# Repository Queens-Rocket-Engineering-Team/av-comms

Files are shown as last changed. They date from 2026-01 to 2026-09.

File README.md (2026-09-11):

# Avionics Communications (Communications Module, Ground Station, etc)
> 2023-2025 Season - Communications Projects

-  Repo contains board's **firmware**, **schematics**, and related **documentation and datasheets**.
-  The **Main** branch contains current functional hardware/software
-  **Branches** contain board revisions/versions or planned features/fixes.
-  If you're contributing, **make sure you're working in a branch other than Main**

### Folder Structure
- [`/Schematics`](./Schematics/) : PCB design files (KiCad V8)  
- [`/Firmware`](./Firmware/) : Arduino C/C++ code (for STM32)
- [`/Datasheets`](./Datasheets/) : Datasheets and reference materials  
- [`.gitignore`](./.gitignore) : Build and temporary files excluded

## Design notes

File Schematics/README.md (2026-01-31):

# Schematics

This directory contains all schematics involved in this iteration of the Avionics Communications System.

## Communications Module
- Facilitates communication to ground station via LoRa

## Kuhglocke Ground Station
- Handheld ground station used for in flight telemetry and recovery

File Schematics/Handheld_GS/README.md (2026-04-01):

# Portable Ground Station

This directory contains the V1.2 revision of the ground station. It no longer has iss several known problems;

### Updates
- Removed I2C ADC, switched to ESP32-ADCs
- Using direct USB+/- for programming, removed uart bridge
- Added V_BCKP for GPS, (copied circuit from gps antenna board)

### Future Suggestions
- Look into using the MAX17043 for battery management
- Look into using TP4056 for battery charging (cheaper)
- switch to a new battery switch cause it breaks

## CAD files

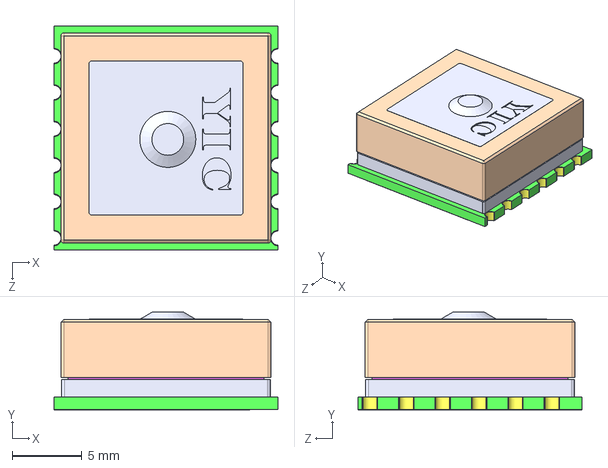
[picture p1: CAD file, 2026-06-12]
Schematics/Handheld_GS/models/STEP_YIC31616GMSGG.STEP
16.0 x 6.97 x 16.0 mm

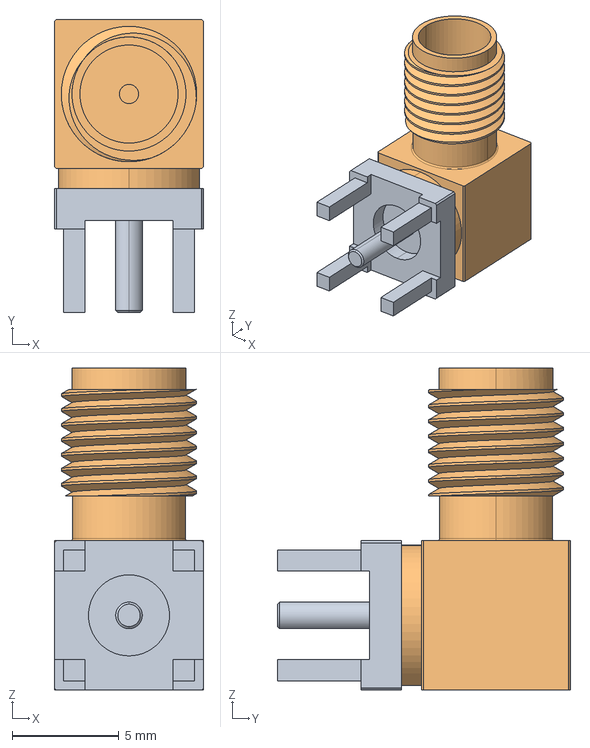
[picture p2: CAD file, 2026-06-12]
Schematics/Handheld_GS/models/pcb_smafra_ht.stp
7.00 x 13.8 x 15.1 mm

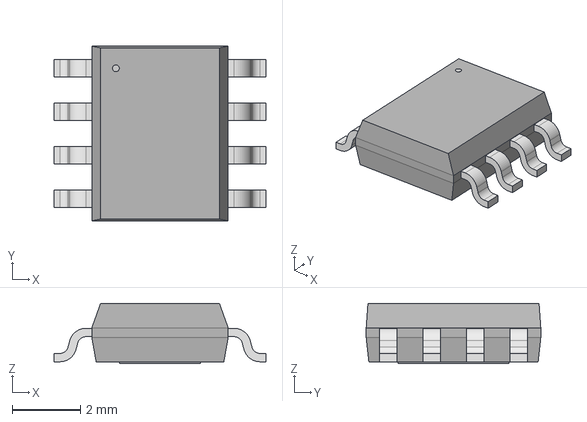
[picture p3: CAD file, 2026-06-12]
Schematics/Handheld_GS/models/ES1_ESOP-8-F__TPK.step
6.20 x 5.11 x 1.75 mm

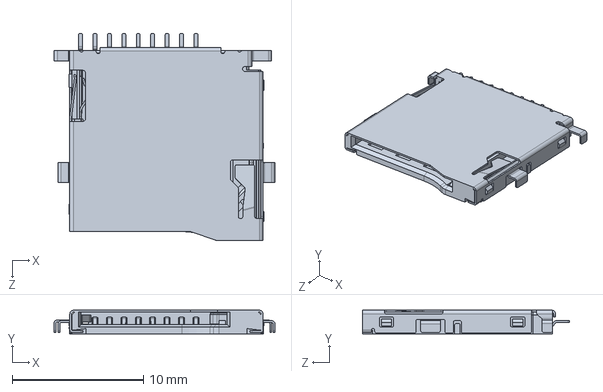
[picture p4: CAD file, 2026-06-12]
Schematics/Handheld_GS/models/Same_Sky_MSD-3-A.step
16.8 x 1.80 x 15.8 mm

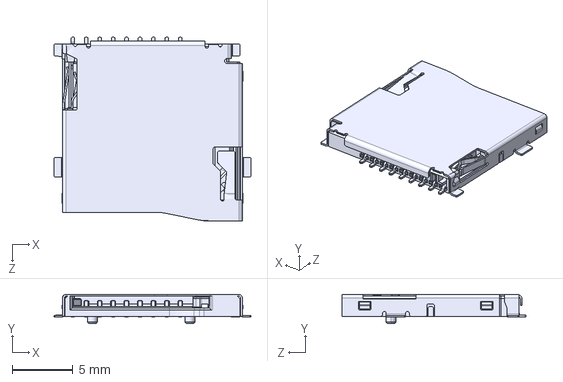
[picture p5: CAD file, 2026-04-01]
Schematics/Handheld_GS/models/MSD-1-A--3DModel-STEP-1.STEP
16.1 x 2.40 x 15.0 mm

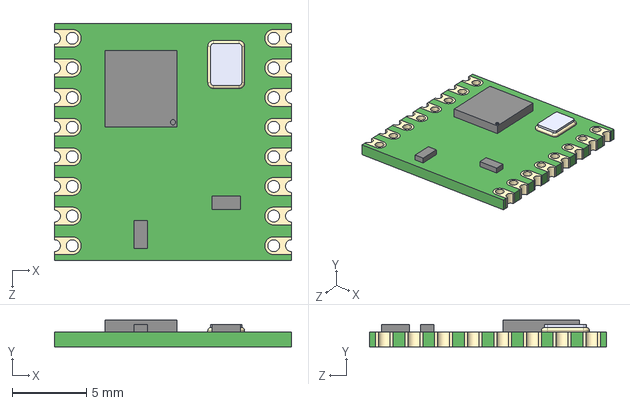
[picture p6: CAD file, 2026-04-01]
Schematics/Handheld_GS/models/RFM95W-915S2--3DModel-STEP-56544.STEP
16.0 x 1.80 x 16.0 mm

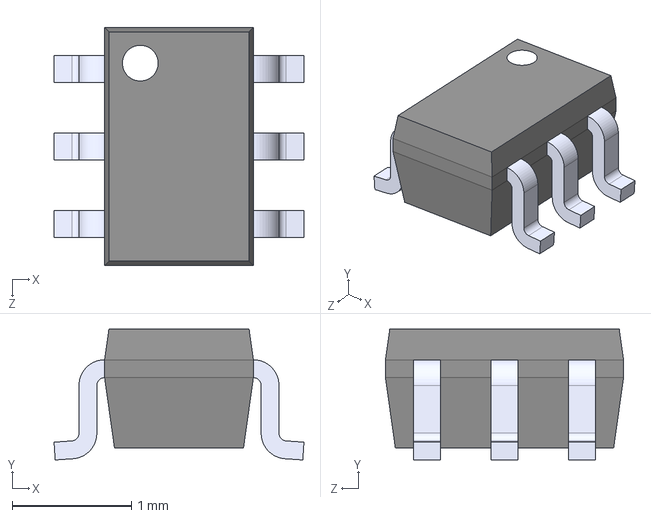
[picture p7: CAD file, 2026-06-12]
Schematics/Handheld_GS/models/LM66100DCKR.step
2.10 x 1.10 x 2.00 mm

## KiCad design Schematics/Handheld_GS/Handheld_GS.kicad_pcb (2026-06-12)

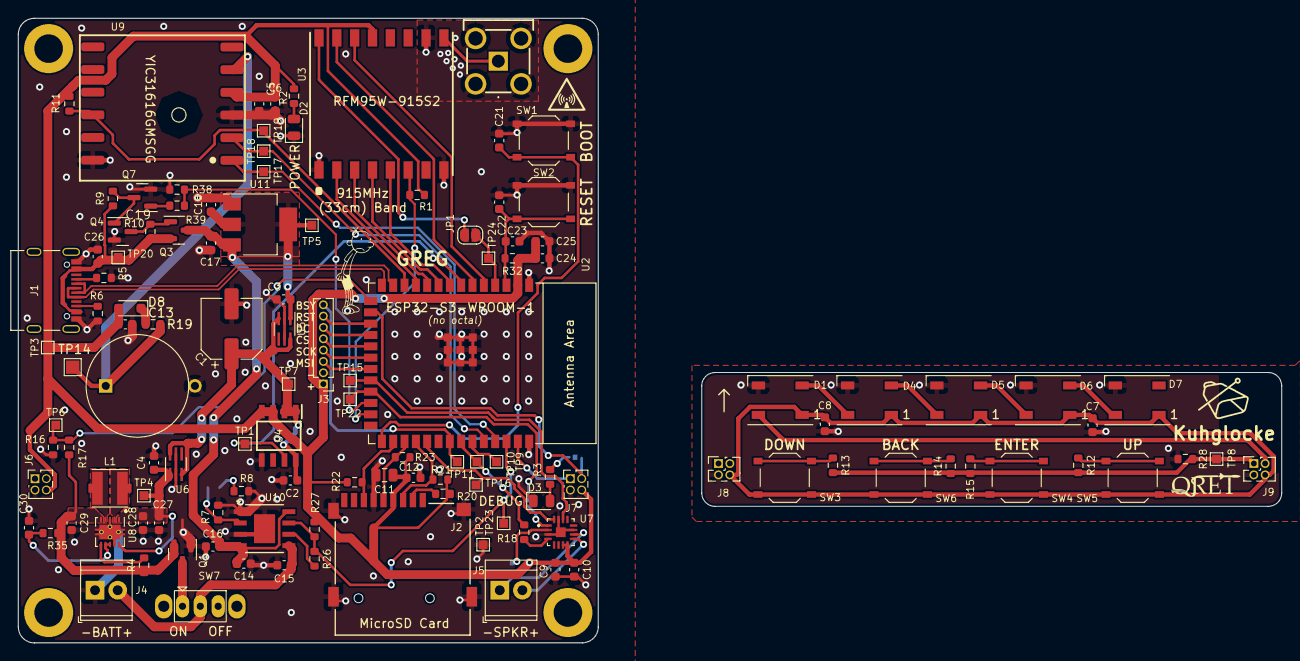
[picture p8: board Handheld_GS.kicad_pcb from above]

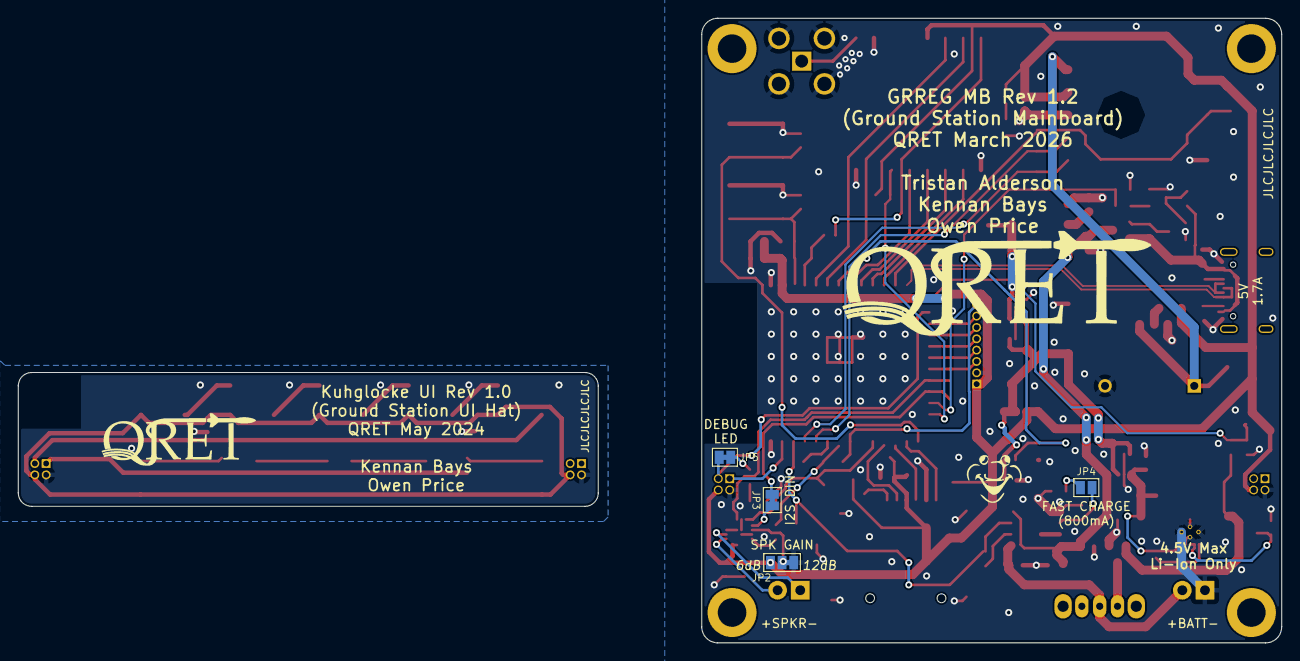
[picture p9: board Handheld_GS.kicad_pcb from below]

Board: 2 copper layers, 65.0 x 70.0 mm, 129 parts (4 on the bottom side), 82 nets.

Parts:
AE1: Antenna; PCB114SMAFRAJA
C1: 100uF; CP_Elec_6.3x5.9
C2, C5, C9, C12, C16, C21, C22, C25, C30: 0.1uF; C_0603_1608Metric
C3, C4, C7, C8, C13, C14, C15, C23: 1uF; C_0603_1608Metric
C6: 4.7uF; C_0603_1608Metric
C10, C17, C18, C24, C26, C27, C28, C29: 10uF; C_0603_1608Metric
C11: 47uF; C_0805_2012Metric
C19: 330mF; CB5R5334HF-ZJP
D1, D4, D5, D6, D7: WS2812B; LED_WS2812B_PLCC4_5.0x5.0mm_P3.2mm
D2: INT_PWR_LED (RED); LED_0805_2012Metric
D3: DB_LED (GRN); LED_0805_2012Metric
D8: 1N5819WS; D_SOD-323_HandSoldering
H1, H2, H3, H4: MountingHole; MountingHole_3.2mm_M3_ISO14580_Pad
J1: USB_C_Female_USB2_Small; USB_C_DB-108PWB
J2: MSD-1-A MicroSD Slot; MicroSD_MSD-1-A
J3: PinHeader_1x08_P1.27mm_Vertical
J4: 1S Li-Ion Cell; TerminalBlock_TE_282834-2_1x02_P2.54mm_Horizontal
J5: Speaker; TerminalBlock_TE_282834-2_1x02_P2.54mm_Horizontal
J6: MB_A; PinSocket_2x02_P1.27mm_Vertical
J7: MB_B; PinSocket_2x02_P1.27mm_Vertical
J8: DB_A; HPH2-A-04-UA_PINS
J9: DB_B; HPH2-A-04-UA_PINS
JP1: DIO2_EN; SolderJumper-2_P1.3mm_Open_RoundedPad1.0x1.5mm
JP2: Gain; SolderJumper-3_P1.3mm_Bridged12_Pad1.0x1.5mm_NumberLabels
JP3: SPK_DIN; SolderJumper-2_P1.3mm_Bridged_Pad1.0x1.5mm
JP4: FastCharge; SolderJumper-2_P1.3mm_Open_Pad1.0x1.5mm
JP5: DB_LED_EN; SolderJumper-2_P1.3mm_Bridged_Pad1.0x1.5mm
L1: 2.2uH; L_Taiyo-Yuden_MD-4040
Q1, Q3: AO3401A; SOT-23
Q4, Q7: AO3400A; SOT-23
R1, R3, R11, R16, R20, R21, R22, R23, R26, R27, R32: 10k; R_0603_1608Metric
R2: 1.8k; R_0603_1608Metric
R4, R9, R18, R38: 100k; R_0603_1608Metric
R5, R6: 5.1k; R_0603_1608Metric
R7: 2.4k; R_0603_1608Metric
R8: 3.9k; R_0603_1608Metric
R10: 51k; R_0603_1608Metric
R12, R39: 510; R_0603_1608Metric
R13, R28: 1k; R_0603_1608Metric
R14: 2k; R_0603_1608Metric
R15: 5.6k; R_0603_1608Metric
R17: 20k; R_0603_1608Metric
R19: 100R; R_0603_1608Metric
R35: 100; R_0603_1608Metric
SW1: SW_ESP_BOOT_MODE; SW_Push_1P1T_XKB_TS-1187A
SW2: SW_ESP_RESET; SW_Push_1P1T_XKB_TS-1187A
SW3: SW_DOWN; SW_Push_1P1T_XKB_TS-1187A
SW4: SW_ENTER; SW_Push_1P1T_XKB_TS-1187A
SW5: SW_UP; SW_Push_1P1T_XKB_TS-1187A
SW6: SW_BACK; SW_Push_1P1T_XKB_TS-1187A
SW7: PWR; SS-12D07-VG 4 NS GA PA
TP1: TP_ISENSE; TestPoint_Pad_1.0x1.0mm
TP2: TP_GND; TestPoint_Pad_1.0x1.0mm
TP3: TP_3V3; TestPoint_Pad_1.0x1.0mm
TP4: TP_VPSU; TestPoint_Pad_1.0x1.0mm
TP5: TP_VUSB; TestPoint_Pad_1.0x1.0mm
TP6: B_SENSE; TestPoint_Pad_1.0x1.0mm
TP7: TP_MUX; TestPoint_Pad_1.0x1.0mm
TP8: TP_BTN; TestPoint_Pad_1.0x1.0mm
TP9: IO42; TestPoint_Pad_1.0x1.0mm
TP10: IO41; TestPoint_Pad_1.0x1.0mm
TP11: IO40; TestPoint_Pad_1.0x1.0mm
TP14: BKP; TestPoint_Pad_1.5x1.5mm
TP15: I2S_LRCLK; TestPoint_Pad_1.0x1.0mm
TP16: I2S_BLCK; TestPoint_Pad_1.0x1.0mm
TP17: GPS_RX; TestPoint_Pad_1.0x1.0mm
TP18: GPS_TX; TestPoint_Pad_1.0x1.0mm
TP19: GPS_RST; TestPoint_Pad_1.0x1.0mm
TP20: 5V_RAW; TestPoint_Pad_1.0x1.0mm
TP22: I2S_DIN; TestPoint_Pad_1.0x1.0mm
TP23: CHRG_STAT; TestPoint_Pad_1.0x1.0mm
TP24: IO4; TestPoint_Pad_1.0x1.0mm
U2: ESP32-S3-WROOM-1
U3: RFM95W-915S2; RFM95W
U4: ACS70331EOLC; SOIC127P600X175-8N
U5, U6: LM66100DCKR; SC-70-6_Handsoldering
U7: MAX98357AETE_T; MAX98357_QFN50P300X300X80-17N
U8: TPS63001DRCR; Texas_DRC0010J_ThermalVias
U9: YIC31616GMSGG GPS; YIC31616GMSGG
U10: TPB4056B2X-ES1R; ES1ESOP-8-F_TPK
U11: AMS1117-3.3; SOT-223-3_TabPin2

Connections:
5V_OFF: R38.1, R39.1, U2.24 (GPIO47/SPICLK_P/SUBSPICLK_P_DIFF)
5V_RAW: C26.2, J1.A4 (VBUS), J1.A9 (VBUS), J1.B4 (VBUS), J1.B9 (VBUS), Q3.2 (S), R9.1, R10.1, TP20.1
+3.3V: C5.2, C6.2, C9.1, C10.1, C11.1, C12.1, C13.1, C24.1, C25.1, D8.2 (A), J2.4 (VDD), J3.1 (VCC), J6.4, J7.4, JP2.3 (B), R1.2, R2.2, R11.1, R20.1, R21.1, R22.1, R23.1, R27.2, R32.1, TP3.1, U2.2 (3V3), U3.13 (3.3V), U4.3 (IP-), U4.4 (IP-), U7.7 (VDD), U7.8 (VDD__1), U9.4 (VCC)
+3.3VA: C7.2, C8.2, D1.1 (VDD), D4.1 (VDD), D5.1 (VDD), D6.1 (VDD), D7.1 (VDD), J8.4, J9.4, SW3.1, SW4.1, SW5.1, SW6.1
+5V: C14.1, C16.2, C17.1, Q3.3 (D), U10.4 (VIN), U10.8 (CE), U11.3 (VI)
+BATT: C29.1, Q1.2 (S), R4.1, R17.1, R35.1, U8.5 (VIN)
/GPS_BCKP: C19.1, R19.2, TP14.1, U9.5 (V_BCKP)
/LA: L1.2, U8.2 (L2)
/LB: L1.1, U8.4 (L1)
ARGB_DATA: J7.3, JP5.1 (A), U2.16 (GPIO46)
ARGB_DATA_DB: D1.4 (DIN), J9.3
BATT_SENSE: R16.1, R17.2, TP6.1, U2.15 (GPIO3/TOUCH3/ADC1_CH2)
BUTTONS: J7.1, U2.39 (GPIO1/TOUCH1/ADC1_CH0)
BUTTONS_DB: J9.1, R12.2, R13.2, R14.1, R15.2, R28.2, TP8.1
CHRG_STAT: R26.2, R27.1, TP23.1, U2.38 (GPIO2/TOUCH2/ADC1_CH1), U10.7 (CHRG)
CLK_SDMMC: J2.5 (CLK), R23.2, U2.29 (SPIIO7/GPIO36/FSPICLK/SUBSPICLK)
CMD_SDMMC: J2.3 (CMD), R21.2, U2.30 (SPIDQS/GPIO37/FSPIQ/SUBSPIQ)
CS_EINK: J3.5 (CS), U2.19 (GPIO11/TOUCH11/ADC2_CH0/FSPID/FSPIIO5/S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)
CS_RF: U2.8 (GPIO15/U0RTS/ADC2_CH4/XTAL_32K_P), U3.5 (NSS)
CURR_SENSE: TP1.1, U2.7 (GPIO7/TOUCH7/ADC1_CH6), U4.7 (VOUT)
D0_SDMMC: J2.7 (DAT0), R22.2, U2.28 (SPIIO6/GPIO35/FSPID/SUBSPID)
DIO0_RF: U2.5 (GPIO5/TOUCH5/ADC1_CH4), U3.14 (DIO0)
DIO1_RF: U2.6 (GPIO6/TOUCH6/ADC1_CH5), U3.15 (DIO1)
DIO2_RF: JP1.2 (B), TP24.1, U2.4 (GPIO4/TOUCH4/ADC1_CH3)
EINK_BUSY: J3.8 (BUSY), TP11.1, U2.33 (MTDO/GPIO40/CLK_OUT2)
EINK_DC: J3.6 (DC), U2.18 (GPIO10/TOUCH10/ADC1_CH9/FSPICS0/FSPIIO4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)
ESP32_EN: C22.2, C23.2, R32.2, SW2.2, U2.3 (EN)
GND: AE1.2 (Shield), C1.2, C2.2, C3.2, C4.2, C5.1, C6.1, C9.2, C10.2, C11.2, C12.2, C13.2, C14.2, C15.1, C16.1, C17.2, C18.2, C19.2, C21.1, C22.1, C23.1, C24.2, C25.2, C26.1, C27.2, C28.2, C29.2, C30.2, D2.1 (K), D3.1 (K), J1.A1 (GND), J1.A12 (GND), J1.B1 (GND), J1.B12 (GND), J2.6 (VSS), J2.10 (SHIELD), J3.2 (GND), J4.1, J6.2, J7.2, JP2.1 (A), Q1.1 (G), Q4.2 (S), Q7.2 (S), R5.2, R6.2, R7.1, R8.2, R16.2, R38.2, SW1.1, SW2.1, TP2.1, U2.1 (GND), U2.40 (GND), U2.41 (GND), U3.1 (GND), U3.8 (GND), U3.10 (GND), U4.5 (GND), U5.2 (GND), U5.5 (ST), U6.2 (GND), U6.5 (ST), U7.3 (GND), U7.11 (GND__1), U7.15 (GND__2), U7.17 (EP), U8.3 (PGND), U8.9 (GND), U8.11 (PGND), U9.3 (GND), U9.12 (GND), U10.1 (TEMP), U10.3 (GND), U10.9 (GND), U11.1 (GND)
GND2: C7.1, C8.1, D1.3 (VSS), D4.3 (VSS), D5.3 (VSS), D6.3 (VSS), D7.3 (VSS), J8.2, J9.2, R28.1
GPIO0: C21.2, SW1.2, U2.27 (GPIO0/BOOT)
GPS_RST: R11.2, TP19.1, U2.12 (GPIO8/TOUCH8/ADC1_CH7/SUBSPICS1), U9.10 (RESET)
I2S_BCLK_SPK: TP16.1, U2.31 (GPIO38/FSPIWP/SUBSPIWP), U7.16 (BCLK)
I2S_DIN_SPK: JP3.2 (B), TP22.1, U2.23 (GPIO21)
I2S_LRCLK_SPK: TP15.1, U2.22 (GPIO14/TOUCH14/ADC2_CH3/FSPIWP/FSPIDQS/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), U7.14 (LRCLK)
MISO_EINK: TP9.1, U2.35 (MTMS/GPIO42)
MISO_RF: U2.11 (GPIO18/U1RXD/ADC2_CH7/CLK_OUT3), U3.2 (MISO)
MOSI_EINK: J3.3 (DIN), U2.21 (GPIO13/TOUCH13/ADC2_CH2/FSPIQ/FSPIIO7/S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)
MOSI_RF: U2.10 (GPIO17/U1TXD/ADC2_CH6), U3.3 (MOSI)
unnamed: AE1.1 (A), U3.9 (ANT)
unnamed: D1.2 (DOUT), D4.4 (DIN)
unnamed: D2.2 (A), R2.1
unnamed: D3.2 (A), R3.1
unnamed: D4.2 (DOUT), D5.4 (DIN)
unnamed: D5.2 (DOUT), D6.4 (DIN)
unnamed: D6.2 (DOUT), D7.4 (DIN)
unnamed: D8.1 (K), R19.1
unnamed: J1.A5 (CC1), R5.1
unnamed: J1.B5 (CC2), R6.1
unnamed: J2.2 (DAT3/CD), R20.2
unnamed: J5.1, U7.10 (OUTN)
unnamed: J5.2, U7.9 (OUTP)
unnamed: JP1.1 (A), U3.16 (DIO2)
unnamed: JP2.2 (C), U7.2 (GAIN_SLOT)
unnamed: JP3.1 (A), U7.1 (DIN)
unnamed: JP4.1 (A), R8.1
unnamed: JP4.2 (B), R7.2, U10.2 (PROG)
unnamed: JP5.2 (B), R3.2
unnamed: Q1.3 (D), SW7.1 (A)
unnamed: Q3.1 (G), Q4.3 (D), R10.2
unnamed: Q4.1 (G), Q7.3 (D), R9.2
unnamed: Q7.1 (G), R39.2
unnamed: R12.1, SW5.2
unnamed: R13.1, SW3.2
unnamed: R14.2, SW6.2
unnamed: R15.1, SW4.2
unnamed: R18.2, U7.4 (SD_MODE)
unnamed: R4.2, U8.6 (EN)
unnamed: C30.1, R35.2, U8.7 (PS/SYNC), U8.8 (VINA)
unnamed: R26.1, U10.6 (STBY)
RAW_BATT: C15.2, J4.2, SW7.2 (B), U10.5 (BAT)
RESET_EINK: J3.7 (RST), U2.17 (GPIO9/TOUCH9/ADC1_CH8/FSPIHD/SUBSPIHD)
RESET_RF: R1.1, U2.25 (GPIO48/SPICLK_N/SUBSPICLK_N_DIFF), U3.6 (RESET)
SCK_EINK: J3.4 (CLK), U2.20 (GPIO12/TOUCH12/ADC2_CH1/FSPICLK/FSPIIO6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)
SCK_RF: U2.9 (GPIO16/U0CTS/ADC2_CH5/XTAL_32K_N), U3.4 (SCK)
SPK_ON: R18.1, TP10.1, U2.34 (MTDI/GPIO41/CLK_OUT1)
UART1_GPS_RX: TP18.1, U2.36 (U0RXD/GPIO44/CLK_OUT2), U9.2 (TXD)
UART1_GPS_TX: TP17.1, U2.37 (U0TXD/GPIO43/CLK_OUT1), U9.1 (RXD)
USB_D+: J1.A6 (D+), J1.B6 (D+), U2.14 (GPIO20/U1CTS/ADC2_CH9/CLK_OUT1/USB_D+)
USB_D-: J1.A7 (D-), J1.B7 (D-), U2.13 (GPIO19/U1RTS/ADC2_CH8/CLK_OUT2/USB_D-)
V_MUX: C1.1, C2.1, TP7.1, U4.1 (IP+), U4.2 (IP+), U4.8 (VCC), U5.3 (*CE), U5.6 (VOUT), U6.3 (*CE), U6.6 (VOUT)
V_PSU: C4.1, C27.1, C28.1, TP4.1, U6.1 (VIN), U8.1 (VOUT), U8.10 (FB)
V_REGUSB: C3.1, C18.1, TP5.1, U5.1 (VIN), U11.2 (VO)

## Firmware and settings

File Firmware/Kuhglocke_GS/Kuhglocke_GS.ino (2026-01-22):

/*
 * Author: Kennan Bays (Kenneract)
 * Created: Aug.2.2024
 * Updated: Jun.11.2025
 * Purpose: Testing firmware for the Kuhglocke ground station
 * Hardware: QRET Kuhglocke ground station V1.0 (ESP32-S3-N16R2; 16MiB Flash (QSPI), 2MiB PSRAM (QSPI))
 * Environment: Arduino IDE 1.8.10, ESP32 Core V2.0.5, ESPtool.py V4.2.1
 *                                                     NOTE: ESPtool.py only compatible with Arduino IDE 1.x
 * 
 * Suggested Configration:
 * - Board: ESP32S3 Dev Module
 * - Upload Speed: 921600
 * - USB Mode: Hardware CDC and JTAG [IMPORTANT]
 * - USB CDC On Boot: Disabled
 * - USB Firmware MSC On Boot: Disabled
 * - USB DFU On Boot: Disabled
 * - Upload Mode: UART0 / Hardware CDC [IMPORTANT]
 * - CPU Frequency: 240MHz (WiFi)
 * - Flash Mode: QIO 80MHz
 * - Flash Size: 16MB (128Mb) [IMPORTANT]
 * - Partition Scheme: 8M with SPIFFS (3MB APP/1.5MB SPIFFS) [IMPORTANT]
 * - Core Debug Level: None
 * - PSRAM: QSPI PSRAM [IMPORTANT]
 * - Arduino Runs On: Core 1 [IMPORTANT]
 * - Events Run On: Core 1 [IMPORTANT]
 * - Erase All Flash Before Sketch Upload: Disabled
 * 
 * Use the ESP32FS.jar plugin for uploading data to SPIFFS
 * 
 * Onboard Peripherals
 *  - Temperature Sensor
 *  - MicroSD Card
 *  - GPS
 *  - LoRa Radio
 *  - Speaker
 *  - I2C ADC
 *    - Battery Sense
 *    - Current Sense
 *  - RGB LEDs
 *  - Batt voltage
 *  - Current sense
 *  
 */


#include "libraries.h"









void setup() {
  // Configure pinmodes
  pinMode(DISABLE_5V_PIN, OUTPUT);
  pinMode(DB_LED_PIN, OUTPUT);
  pinMode(GPS_RESET_PIN, OUTPUT);
  digitalWrite(GPS_RESET_PIN, HIGH); //TODO: NESSESARY??
  pinMode(MENU_BTNS_PIN, INPUT);
  pinMode(CHRG_STAT_PIN, INPUT);
  analogReadResolution(12);

  // Ensure USB mode is PWR+DATA by default
  setUSBDataOnlyMode(false);

  // Add WS2812B
  rgbLEDs.begin(); // initialize WS2812Bs
  setRGB(0,0,0);
  setLEDBrightness(DEFAULT_LED_BRIGHTNESS);
  // Set power LED to "loading"
  setRGB(0,128,32,0);

  // Start USB Serial
  Serial.begin(USB_BAUD);

  // Prepare SPI busses
  epdSPI.begin(EINK_SCK_PIN, EINK_MISO_PIN, EINK_MOSI_PIN, EINK_CS_PIN);
  rfmSPI.begin(RF_SCK_PIN, RF_MISO_PIN, RF_MOSI_PIN, RF_CS_PIN);
  pinMode(epdSPI.pinSS(), OUTPUT);
  pinMode(rfmSPI.pinSS(), OUTPUT);

  // Initialize E-Paper Display (EPD)
  display.init(EPD_BAUD, true, 2, false, epdSPI, SPISettings(EPD_SPI_CLOCK, MSBFIRST, SPI_MODE0));
  display.setRotation(1);

  display.setTextColor(GxEPD_BLACK);
  display.firstPage();
  do {
    display.fillScreen(GxEPD_WHITE);
    display.setTextSize(1);
    display.print("QRET Kuhglocke    FW=");
    display.println(FIRMWARE_VERSION);
    display.setCursor(30,20);
    display.setTextSize(7);
    display.println("QRET");
    display.setTextSize(2);
    display.println("     Loading");

    display.setTextSize(1);
    display.setCursor(0,112);
    display.println("POWER  BATT    RADIO   SRADOK   GPS FIX");
    
  } while (display.nextPage());

  // Configure I2C Bus
  Wire.begin(I2C_SDA_PIN, I2C_SCL_PIN);
  Wire.setClock(I2C_SPEED);

  // Initialize MicroSD card (1-bit mode)
  SD_MMC.setPins(SDMMC_CLK_PIN, SDMMC_CMD_PIN, SDMMC_D0_PIN);
  if (!SD_MMC.begin("/sdcard", true)) {
    Serial.println("[WARN] MicroSD Card Mount Failed");
    //while(true);
  } else {
    Serial.println("SD: Card Mount Success");
    makeNextSDLog();
    writeToSDLog("Kuhglocke SD card initialized");
  }//if (SD OK)

  // Initialize NAU7802 ADC
  initNAU7802();

  // Initialize GPS
  gpsInit(); 

  // Initialize RFM95 Radio
  rfmInit();

  // Initialize SPIFFS
  if(!SPIFFS.begin(true)){
    Serial.println("An Error has occurred while mounting SPIFFS");
    return;
  }//if

  // Launch WiFi AP
  WiFi.softAP(AP_SSID, AP_PASSWORD, WIFI_CHANNEL);
  WiFi.setTxPower(WIFI_TX_POWER);
  IPAddress IP = WiFi.softAPIP();
  Serial.print("WiFi AP IP address: ");
  Serial.println(IP);

  // Configure Async web server
  configWebServer();
  webServer.begin();

  
  // Launch background task for Core 0
  xTaskCreatePinnedToCore(
      loopAltCoreHandler,   // Task function
      "Core0Loop",          // Name of the task
      ALT_CORE_STACKS_SIZE, // Stack size
      NULL,                 // Task input parameter
      1,                    // Priority of the task
      &Core0Task,           // Task handle
      0                     // Core number
  );
  

  // Set power LED to "ready"
  setRGB(0,0,128,0); //Turn on power LED
  Serial.println("Kuhglocke Initialization Complete!");
  
}//setup()


/*
 * Code to run repeatedly
 */
void loop() {
  // Note loop start time
  uint32_t loopStart = millis();
  
  //setRGB(4, 64,0,0);
  //delay(50);
  //setRGB(4, 0,0,0);
  //delay(1000);

  
  handleGPS();
  handleReadSensors();
  handleLEDs();
  //Serial.print("BTNS=");
  //Serial.println(analogRead(MENU_BTNS_PIN));
  if (analogRead(MENU_BTNS_PIN) > 40) {
    setLEDBrightness(255);
    //setRGB(4, 255,255,255);
    //writeToSDLog("This is an example log file line.");
  } else {
    setLEDBrightness(DEFAULT_LED_BRIGHTNESS);
    //setRGB(4, 0,0,0);
  }

  // Check for incoming RFM95 packets
  if (rfmReceivedFlag) {
    // Reset flag
    rfmReceivedFlag = false;
    onRFMReceive();
  }//if (rfm recv)

  // Note loop execution time
  uint16_t core1LoopTime = (millis()-loopStart);
  core1LoopFilter.AddValue(core1LoopTime);
  if (core1LoopTime > maxCore1LoopTime) {maxCore1LoopTime = core1LoopTime;}

  if (millis() - lastEPDUpdate > EPD_UPDATE_INT) {
    lastEPDUpdate = millis();
    //updateEPD();
  }

}//loop()


/*
 * Run as a task on Core0; runs the alternate loop
 * function indefinitely.
 */
void loopAltCoreHandler(void * pvParameters) {
  Serial.println("Starting background thread on Core0");
  while (true) {
    loopAltCore();
  }//while
}//loopAltCoreHandler()


/*
 * Like loop(), but runs on Core0 of the ESP32
 * 
 * Make sure you use a MUTEX when exchanging
 * lots of info with Core1.
 * 
 * NOTE: STACK SIZE IS LIMITED HERE.
 */
void loopAltCore() {
  // Note loop start time
  uint32_t loopStart = millis();
  
//  Serial.print("AltCore Loop: ");
//  Serial.println(core0FreeStack);
//  delay(100);

  // Check to update EPD
  if (millis() - lastEPDUpdate > EPD_UPDATE_INT) {
    lastEPDUpdate = millis();
    updateEPD();
  }//if

  //for reading sensors or updating the EPD, and maybe playing audio

  // Note free stack space
  core0FreeStack = uxTaskGetStackHighWaterMark(NULL);
  // Note loop execution time
  core0LoopTime = (millis()-loopStart);
  if (core0LoopTime > maxCore0LoopTime) {maxCore0LoopTime = core0LoopTime;}
}//loopAltCore()

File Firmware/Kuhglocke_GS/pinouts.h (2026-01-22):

#pragma once

/*
 * Pin definitions for the Kuhglocke ground station (Rev 1.0)
 */

#define GPS_TX_PIN 20
#define GPS_RX_PIN 19
#define GPS_RESET_PIN 8

#define MENU_BTNS_PIN 1
#define ARGB_DATA_PIN 46
#define DB_LED_PIN ARGB_DATA_PIN //same pin as RGB

#define CHRG_STAT_PIN 2
#define DISABLE_5V_PIN 3

#define RF_DIO2_PIN 4
#define RF_DIO0_PIN 5
#define RF_DIO1_PIN 6
#define RF_RESET_PIN 7
#define RF_MOSI_PIN 17
#define RF_MISO_PIN 18
#define RF_CS_PIN 15
#define RF_SCK_PIN 16

#define EINK_RESET_PIN 9
#define EINK_DC_PIN 10
#define EINK_CS_PIN 11
#define EINK_SCK_PIN 12
#define EINK_MOSI_PIN 13
#define EINK_MISO_PIN 42
#define EINK_BUSY_PIN 40

#define SPK_I2S_LRCLK_PIN 14
#define SPK_I2S_DIN_PIN 21
#define SPK_I2S_BCLK_PIN 38
#define SPK_ON_PIN 41

#define SDMMC_CMD_PIN 35
#define SDMMC_CLK_PIN 36
#define SDMMC_D0_PIN 37

#define I2C_SCL_PIN 47
#define I2C_SDA_PIN 48
#define NAU7802_ADDR 0x2A
#define P3T1755_ADDR 0x48

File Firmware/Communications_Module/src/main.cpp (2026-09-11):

#include "node.h"

#include <IWatchdog.h>
#include <logger.h>
#include <SoftwareSerial.h>
#include <SPI.h>

#include <aim_file_system.h>
#include <aim_flight_recorder.h>
#ifndef FLIGHT_BUILD
#include <aim_console.h>
#endif

static constexpr uint32_t kWatchdogTimeoutUs  = 10000000U; // 10 seconds timeout
static constexpr uint8_t  kMaxRxFramesPerLoop = 8U;
static constexpr uint32_t kLivenessTimeoutMs  = 10000U;  // node considered dead after 10 s silent

static AimStm32CanCore g_canHw(node::kCanBaud, CAN1);
static AimNetwork g_aim(&g_canHw, node::kSource);
static SoftwareSerial g_serial(pins::kSerialRx, pins::kSerialTx);
static Logger g_log(g_serial, static_cast<uint8_t>(node::kSource), LogLevel::INFO);

// Flash on SPI2: MOSI=PB15, MISO=PB14, SCLK=PB13, CS=PB12 (see pinouts.h).
static SPIClass g_flashSpi(pins::kSpiMosi, pins::kSpiMiso, pins::kSpiSclk);
static SpiNorFlashDriver g_flashDriver(pins::kFlashCs, g_flashSpi);
static AimFileSystem g_fs(&g_flashDriver);
static AimFlightRecorder g_recorder(g_fs, kLogCols, kLogOriginRefresh, kLogMaxSize, kLogHeaders);

static void serviceCanRx(void) {
  const uint32_t nowMs = millis();
  for (uint8_t i = 0U; i < kMaxRxFramesPerLoop; i++) {
    aim::Msg m = {};
    if (!g_aim.receive(m)) break;
    nodeOnRx(m, nowMs);
  }
}

#ifndef FLIGHT_BUILD
static void hookStatus(Stream& out) {
  out.print("name=");
  out.print(node::kName);
  out.print(" logMask=0x");
  out.print(static_cast<unsigned>(g_log.filterMask()), HEX);
  out.print(" syncedMs=");
  out.print(static_cast<unsigned long>(g_aim.syncedMillis()));
  out.print(" version=");
  out.print(aim::kNetworkVersionString);
  out.print(" schema=");
  out.print(static_cast<unsigned>(aim::kSchemaVersion));
  out.print(" build=");
  out.print(__DATE__);
  out.print(" ");
  out.println(__TIME__);
}
#endif  // FLIGHT_BUILD

void setup(void) {
  uint32_t start = millis();
  g_serial.begin(node::kSerialBaud);
  g_logger = &g_log;
  g_log.setFilterMask(static_cast<uint8_t>(LogLevel::INFO));  // INFO only

  LOG_INFO("Boot %s source=%u", node::kName, static_cast<unsigned>(aim::Source::Comms));

  // Comms is the downlink aggregator: accept everything worth forwarding, plus
  // Time (to discipline its clock from the master) and Heartbeat (liveness).
  if (!g_aim.begin(aim::classBit(aim::Class::Sensor) |
                   aim::classBit(aim::Class::State) |
                   aim::classBit(aim::Class::Event) |
                   aim::classBit(aim::Class::Heartbeat) |
                   aim::classBit(aim::Class::Time))) {
    LOG_ERROR("CAN init failed");
  }

  if (!g_fs.begin()) {
    LOG_WARN("Filesystem mount failed");
  } else if (!g_recorder.begin()) {
    LOG_WARN("Recorder init failed");
  } else {
    LOG_INFO("Flash ready");
  }

#ifndef FLIGHT_BUILD
  uint8_t nodeHookCount = 0U;
  const AimConsoleHook* nodeHooks = nodeConsoleHooks(nodeHookCount);

  static AimConsoleHook combinedHooks[8];
  uint8_t totalHooks = 0;
  combinedHooks[totalHooks++] = {'s', "status", hookStatus};
  for (uint8_t i = 0; i < nodeHookCount && totalHooks < 8; i++) {
    combinedHooks[totalHooks++] = nodeHooks[i];
  }
  aimConsoleInit(g_serial, g_fs, g_recorder, node::kName, combinedHooks, totalHooks);
  g_serial.println("Console ready. d=enter debug");
#endif

  nodeInit();
  IWatchdog.begin(kWatchdogTimeoutUs);
  LOG_INFO("Watchdog ready (%lus timeout)", static_cast<unsigned long>(kWatchdogTimeoutUs / 1000000U));

  const uint32_t end = millis();
  LOG_INFO("Setup complete (total=%lums)", static_cast<unsigned long>(end - start));
}

void loop(void) {
  const uint32_t nowMs = millis();

  serviceCanRx();
  nodeUpdate(nowMs);
  if (!aimConsoleIsActive()) {
    nodeServiceLog(nowMs, g_recorder);
  }
  nodeServiceCanTx(nowMs, g_aim);
  g_aim.service(nowMs, nodeCurrentState(), nodeErrorBits());   // heartbeat fills bus silence

#ifndef FLIGHT_BUILD
  aimConsoleService();                            // owns console + flash dump/erase
#endif

  IWatchdog.reload();
}

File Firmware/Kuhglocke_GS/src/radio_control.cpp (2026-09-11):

#include "radio_control.h"
#include "pinouts.h"
#include "global.h"
#include "user_interface.h"
#include <SPI.h>
#include <RadioLib.h>
#include <aim_catalog.h>
#include <lora_link.h>

// Static state variables
static double s_freqOpts[] = {902.0, 904.5, 928.0};
static uint8_t s_freqSelected = 1;

static constexpr uint8_t s_numBandwidthOpts = 10;
static double s_bandwidthOpts[s_numBandwidthOpts] = {7.8, 10.4, 15.6, 20.8, 31.25, 41.7, 62.5, 125, 250, 500};
static uint8_t s_bandwidthSelected = 8; // 250 kHz

static constexpr uint8_t s_numSpreadOpts = 6;
static int32_t s_spreadOpts[s_numSpreadOpts] = {7, 8, 9, 10, 11, 12};
static uint8_t s_spreadSelected = 1; // SF8

static constexpr uint8_t s_numCodingOpts = 4;
static int32_t s_codingOpts[s_numCodingOpts] = {5, 6, 7, 8};
static uint8_t s_codingSelected = 0; // CR 4/5 (5)

static volatile uint32_t s_rfmLastRFReceived = 0;
static volatile int16_t s_rfmLastRSSI = 0;
static volatile float s_rfmLastSNR = 0;
static volatile int32_t s_rfmLastFreqErr = 0;

static volatile int32_t s_rocketGPSLat = 0;
static volatile int32_t s_rocketGPSLon = 0;
static volatile uint8_t s_rocketGPSSats = 0;
static volatile bool    s_rocketGpsFix = false;
static volatile int32_t s_rocketAltitude = 0;
static volatile float   s_rocketAccelG = 0.0f;
static volatile float   s_rocketBattVolts = 0.0f;
static volatile uint8_t s_rocketFetStatus = 0;
static volatile uint8_t s_rocketFlightState = 0;

static int32_t s_curFreqOffset = 0;
static volatile bool s_rfmReceivedFlag = false;

static volatile uint8_t s_rocketLivenessMask = 0;

static uint32_t s_packetCount = 0;

// Radio editing state
static bool    s_editActive = false;
static uint8_t s_editParam = 0;       // 0=freq, 1=BW, 2=SF, 3=CR
static uint8_t s_editFreqIdx;
static uint8_t s_editBwIdx;
static uint8_t s_editSfIdx;
static uint8_t s_editCrIdx;

// Mutex for cross-core synchronization
static portMUX_TYPE s_rocketMux = portMUX_INITIALIZER_UNLOCKED;

// SPI + Radio Objects
static SPIClass s_rfmSPI(HSPI);
static SPISettings s_rfmSPISettings(kRfmSpiClock, MSBFIRST, SPI_MODE0);
static Module s_radioModule(pins::kRfCs, pins::kRfDio0, pins::kRfReset, pins::kRfDio1, s_rfmSPI, s_rfmSPISettings);
static RFM95 s_radio(&s_radioModule);

static void byteArrayToHexStr(const byte* byteArray, int length, char* outBuf, size_t maxLen) {
  if (static_cast<size_t>(length * 2 + 1) > maxLen) {
    if (maxLen > 0) outBuf[0] = '\0';
    return;
  }
  static const char hex[] = "0123456789ABCDEF";
  for (int i = 0; i < length; i++) {
    uint8_t b = byteArray[i];
    outBuf[i * 2] = hex[(b >> 4) & 0x0F];
    outBuf[i * 2 + 1] = hex[b & 0x0F];
  }
  outBuf[length * 2] = '\0';
}

#if defined(ESP8266) || defined(ESP32)
  ICACHE_RAM_ATTR
#endif
void setFlag(void) {
  s_rfmReceivedFlag = true;
}

bool isRFMConnected() {
  portENTER_CRITICAL(&s_rocketMux);
  uint32_t lastRF = s_rfmLastRFReceived;
  portEXIT_CRITICAL(&s_rocketMux);
  return (millis() - lastRF < kRfmConnectedTimeout);
}

void rfmInit() {
  // Initialize SPI Bus
  s_rfmSPI.begin(pins::kRfSck, pins::kRfMiso, pins::kRfMosi, pins::kRfCs);
  pinMode(s_rfmSPI.pinSS(), OUTPUT);

  setRGB(2, 255, 0, 0, true); // set RF light to RED
  Serial.print(F("RFM95: Initializing ... "));
  s_radio.reset();
  delay(100);
  int state = s_radio.begin();
  if (state == RADIOLIB_ERR_NONE) {
    Serial.println(F("success!"));
  } else {
    Serial.print(F("failed, code "));
    Serial.println(state);
    setRGB(2, 255, 0, 0, true); // set RF light to RED
    return; // degraded mode: return instead of hanging
  }

  s_radio.setDio0Action(setFlag, RISING);

  double baseFreq = s_freqOpts[s_freqSelected];
  double freqOffset = (s_curFreqOffset / 1000000.0); // Hz -> MHz
  
  s_radio.setFrequency(baseFreq + freqOffset);
  s_radio.setBandwidth(s_bandwidthOpts[s_bandwidthSelected]);
  s_radio.setSpreadingFactor(s_spreadOpts[s_spreadSelected]);
  s_radio.setCodingRate(s_codingOpts[s_codingSelected]);
  s_radio.setSyncWord(0x12);
  s_radio.setPreambleLength(8);
  s_radio.setCRC(true);
  s_radio.explicitHeader();

  state = s_radio.startReceive();
  if (state == RADIOLIB_ERR_NONE) {
    Serial.println(F("Radio Listening Active"));
  } else {
    Serial.print(F("failed starting listening, code "));
    Serial.println(state);
  }
}

void onRFMReceive() {
  uint8_t rfmPayload[32];
  size_t len = s_radio.getPacketLength();
  if (len > sizeof(rfmPayload)) len = sizeof(rfmPayload);

  int state = s_radio.readData(rfmPayload, len);

  // Restart receiver immediately
  s_radio.startReceive();

  if (state != RADIOLIB_ERR_NONE) {
    if (state != RADIOLIB_ERR_CRC_MISMATCH) {
      Serial.print("Receive failed, code ");
      Serial.println(state);
    }
    return;
  }

  uint32_t nowMs = millis();
  s_packetCount++;

  portENTER_CRITICAL(&s_rocketMux);

  if (len >= lora::kFastPacketSize && lora::isFastFrame(rfmPayload)) {
    // Fast Frame (13 Bytes)
    lora::FastFrame fastPkt = lora::decodeFast(rfmPayload);
    s_rocketAltitude    = fastPkt.alt_m;
    s_rocketAccelG      = fastPkt.getAccelG();
    s_rocketGPSLat      = fastPkt.gps_lat;
    s_rocketGPSLon      = fastPkt.gps_lon;
    s_rocketFlightState = fastPkt.header.flight_state;
  } else if (len >= lora::kSlowPacketSize && lora::isSlowFrame(rfmPayload)) {
    // Slow Frame (5 Bytes)
    lora::SlowFrame slowPkt = lora::decodeSlow(rfmPayload);
    s_rocketGPSSats      = slowPkt.getSatellites();
    s_rocketGpsFix       = slowPkt.hasGpsFix();
    s_rocketBattVolts    = slowPkt.getBatteryVolts();
    s_rocketLivenessMask = slowPkt.liveness;
    s_rocketFetStatus    = slowPkt.fet_status;
    s_rocketFlightState  = slowPkt.header.flight_state;
  }

  s_rfmLastRFReceived = nowMs;
  s_rfmLastRSSI = s_radio.getRSSI();
  s_rfmLastSNR = s_radio.getSNR();
  s_rfmLastFreqErr = s_radio.getFrequencyError();
  portEXIT_CRITICAL(&s_rocketMux);

  triggerRFFlash();

  char hexBuf[65];
  byteArrayToHexStr(rfmPayload, len, hexBuf, sizeof(hexBuf));

  char logBuf[100];
  snprintf(logBuf, sizeof(logBuf), "RocketPacket:%u,%d,%.1f,%d,%s",
           nowMs,
           s_rfmLastRSSI,
           s_rfmLastSNR,
           s_rfmLastFreqErr,
           hexBuf);
  writeToSDLog(logBuf);

  char logBuf2[100];
  snprintf(logBuf2, sizeof(logBuf2), "RocketData:%u,%.6f,%.6f,%.2f,%.2f",
           getRocketGPSSats(),
           getRocketLatDeg(),
           getRocketLonDeg(),
           getRocketAltitudeMeters(),
           static_cast<double>(getRocketAccelG()));
  writeToSDLog(logBuf2);
}

bool getRfmReceivedFlag() {
  return s_rfmReceivedFlag;
}

void clearRfmReceivedFlag() {
  s_rfmReceivedFlag = false;
}

double getRadioFreq() {
  return s_freqOpts[s_freqSelected];
}
// NOTE: Kept for future manual tuning / local menu support
double getRadioBandwidth() {
  return s_bandwidthOpts[s_bandwidthSelected];
}

// NOTE: Kept for future manual tuning / local menu support
int32_t getRadioSF() {
  return s_spreadOpts[s_spreadSelected];
}
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

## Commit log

2026-01-22 Split Kuhglocke_GS into modules (GPS/global/radio/screen/sensors/UI)
2026-01-31 init commit for migrating avionics comms devices to dedicated repo - updated datasheets links to local file - missing exact LoRaSX162 datasheet
    [10018784-10210TLF.step, 10118194-0001LF-USB.step, 8890445_SWD_PINS.stp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]
2026-02-04 more optimized
    [Register_mapping.xlsx, test.csv]
2026-03-25 start of new migrated ground station project
    [Handheld_GS.kicad_pcb, Handheld_GS.kicad_sch]
2026-03-28 Updated ground station with suggest changes and more, routing done
    [ESP32-S3-WROOM-1.STEP, ESP32-S3-WROOM-1U.STEP, Handheld_GS.kicad_pcb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]
2026-03-30 Update Silkscreen and Added some 3D models
    [Handheld_GS.kicad_pcb, MSD-1-A--3DModel-STEP-1.STEP, RFM95W-915S2--3DModel-STEP-56544.STEP]
2026-03-31 added silkscreen for eink pins
    [Handheld_GS.kicad_pcb, Handheld_GS.kicad_sch]
2026-04-01 update datasheet referencing
    [Communications_Module.kicad_sch]
2026-05-01 add 3d models to all parts
    [ES1_ESOP-8-F__TPK.step, ESP32-S3-WROOM-1.STEP, ESP32-S3-WROOM-1U.STEP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]
2026-06-14 fix(kuhglocke): drop dead freqOffset line, memcpy callsign, fix endpoint responses
    Radio_control.cpp: removes the dead first freqOffset calculation that was
    immediately overwritten; collapses 6 individual rocketCallsign byte assignments
    into memcpy(rocketCallsign, rfmPayload, 6).
    WebServerEndpoints.ino: FreqUp/FreqDown/RadioReload were incorrectly responding
    with style.css; fixed to request->send(200, "text/plain", "OK").
    [Radio_control.cpp, WebServerEndpoints.ino]
2026-06-14 fw(comms): migrate Communications_Module to AIM Network v0.6.x
    Drops bespoke console.cpp/h in favour of shared aim_console library.
    Rewrites node.h/node.cpp to v0.6.x node convention: nodeInit/nodeUpdate/
    nodeServiceCanTx public surface, liveness tracker in node.cpp, namespace node::
    constexpr identity, namespace pins:: constexpr pinout. Thins main.cpp to
    globals + setup + loop only — TimeSync TX logic moves from main.cpp into
    nodeServiceCanTx(). Adds pinouts.h with full STM32F103CBT6 pin map.
2026-06-14 fw(kuhglocke): migrate pinouts from #define to namespace pins:: constexpr
    Converts all pin macros in pinouts.h to constexpr uint8_t in namespace pins::
    with kCamelCase names, grouped by peripheral. Updates all call sites across
    GPS.cpp, Global.cpp, Kuhglocke_GS.ino, Sensor_handling.cpp, User_interface.cpp,
    and battery_managment.cpp to use pins::k* references.
2026-06-14 feat(comms): integrate dynamic state reporting and low-power event subscription
2026-06-16 Phase 1: Migrate Kuhglocke GS to PlatformIO and fix radio-SPI bug
    [partitions.csv]
2026-06-16 Phase 3: Integrate aim_catalog.h LoRa decode and forward aim::Msg framed records
2026-06-16 Phase 3.5: Commit scaling correctness fixes from working tree
    [GPS.cpp, Radio_control.cpp]
2026-06-16 Kuhglocke_GS: Phase 4 — Retire web server and integrate QLCP uplink
    [partitions.csv]
2026-06-18 Communications: pass nowMs into service()
    Match the updated AimNetwork::service(nowMs, state, errorBits) signature.
    [main.cpp]
2026-06-21 Communications: trim self-tracking from liveness, clean up node layout
    Comms no longer tracks itself in the liveness table (kTrackedNodes 6→5).
    Reorder functions to match node convention, apply naming cleanup, and
    tighten console hook registration.
    [main.cpp, node.cpp, node.h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]
2026-07-20 Migration: Integrate v0.7.0 hardware drivers in Comms module
2026-07-24 refactor(telemetry): streamline lora encoding, fix pressure scaling, and remove dead velocity code
    - Replace raw memcpy in comms node with wire-native FastFrame setters
    - Fix pressure scaling mismatch in setPressureFromWire (divide CAN PSI*100 by 10 for FastFrame PSI*10)
    - Unpack AccelG and Chamber Pressure in Ground Station (Kuhglocke) and forward via QLCP uplink
    - Delete unused dead velocity calculation, state, display, and log entries
    [gps.cpp, node.cpp, node.h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]
2026-07-24 docs(qlcp): align JSON schema and sensor_id mapping with AIM v0.7.0 contracts
    - Replace deprecated Vel field with Accel (G) and Chamber (PSI) in kBoardQlcpConfigJson
    - Align QLCP sensor_id array indexing: 0:Lat, 1:Lon, 2:Alt, 3:Accel, 4:Chamber, 5:Sats, 6-10:NodeLiveness
    [qlcp_uplink.cpp]
2026-08-12 refactor(lora_link): update binary wire format to 13B Fast / 5B Slow layout
2026-08-12 feat(comms): reconfigure LoRa timers to 10Hz/0.2Hz and set BW:500kHz / SF10
2026-08-12 refactor(qlcp): update QLCP schema to 23 sensors and remove PT204 chamber channel
2026-08-18 fix(comms): fixed-rate jobs (10 Hz fast / 0.5 Hz slow LoRa, 10 Hz log), watchdog 10 s armed after init
    Pre-launch 2026-08-19 build against av-libraries single-rate Job.
    [main.cpp, node.cpp]
2026-08-19 chore(comms): pad build — INFO-only logging
2026-08-19 switch to debug log
